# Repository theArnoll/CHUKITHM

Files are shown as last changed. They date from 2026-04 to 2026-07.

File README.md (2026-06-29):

# A touch controller based on a Japanese Arcade

English version | [繁體中文版本 (Traditional Chinese version)](README_zh-TW.md)

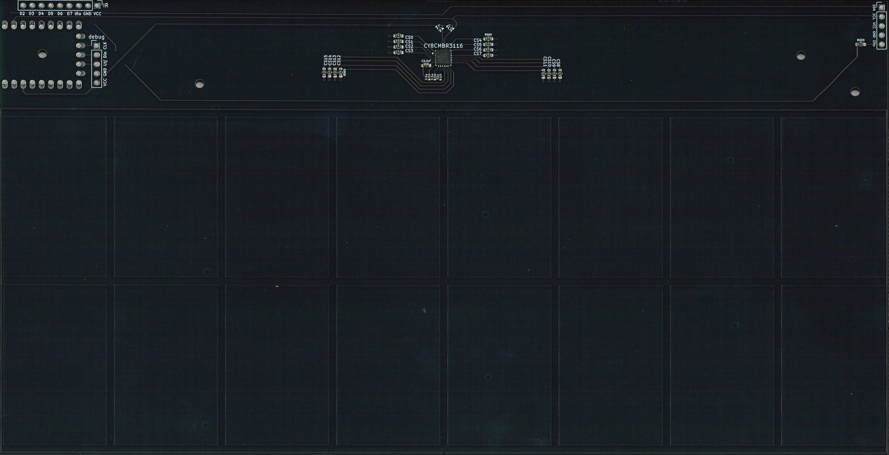
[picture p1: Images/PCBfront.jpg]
PCB Front image

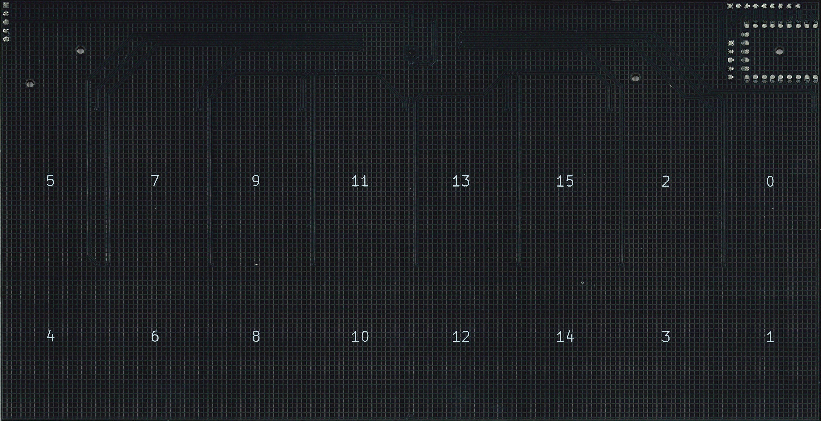
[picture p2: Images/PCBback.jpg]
PCB Back image


## Table of Contents

- [A touch controller based on a Japanese Arcade](#a-touch-controller-based-on-a-japanese-arcade)
  - [Table of Contents](#table-of-contents)
  - [BOM](#bom)
  - [Development platform](#development-platform)
    - [This project is develop with PlatformIO + Arduino C++ code](#this-project-is-develop-with-platformio--arduino-c-code)
  - [Third Party Libraries](#third-party-libraries)
  - [Sensing Concepts, PCB Design, and Dimensional References (Japanese)](#sensing-concepts-pcb-design-and-dimensional-references-japanese)
  - [Usage](#usage)
    - [Software Prerequisite](#software-prerequisite)
    - [Step](#step)
    - [Enabling Keyboard Input](#enabling-keyboard-input)
  - [Prototype Touchpad Making Step](#prototype-touchpad-making-step)
  - [Program flow chart](#program-flow-chart)
    - [Config](#config)
    - [Running code (`CY8C_code.ino`)](#running-code-cy8c_codeino)
  - [Development stage](#development-stage)
  - [AI Usage \& Attribution](#ai-usage--attribution)

## BOM

1. [PCB](./PCB/FormalPCB/Touchpad.kicad_pcb) × 2
   1. CY8CMBR3116 × 1
   2. 0.1uF × 2
   3. 1uF × 1
   4. 2.2nF X7R × 1
   5. 4.7kΩ × 2
   6. 560Ω × 16
2. IR LED × 6 `! Function haven't implented yet`
3. ~IRM-3638~ TSSP58038 IR reciever × 6 `! Function haven't implented yet, likely to switch to TSSP58038`
4. RP2040-Zero × 1 (Refer as RP2040 below)
   1. Machined Pin Header 9 pin × 2
   2. Machined Female Header 9 pin × 2
   3. Machined Pin Header 5 pin × 1
   4. Machined Female Header 5 pin × 1
5. [Acrylic case](./Case/Acrylic.dwg) for touch pads (2mm thick) × 2
   1. [Acrylic cap](./Case/AcrylicCap.dwg) for covering CY8CMBR3116 (2mm thick) × 1
   2. M2 screw (10mm length) × 6
      1. M2 Hex Nut × 6
      2. M2 Washer (Rubber recommended) × 6
   3. M3 screw (≥9mm length) × 7
      1. M3 Hex Nut × 7
      2. M3 Washer (Rubber recommended) × 7

    2mm thick acrylic × 2 + 1.6mm PCB = 5.6mm thick in total.
    5.6mm + 1.6mm M2 nut + 0.5mm rubber washer = 7.7mm
    5.6mm + 2.4mm M3 nut + 0.5mm rubber washer = 8.5mm
<!-- TODO: update IR info here after IR has been implented -->

<details>

<summary>Using test PCB</summary>

1. Testing PCB [motherboard type B](./PCB/TestPCB/TestMotherboardB.kicad_pcb) × 1
2. Testing PCB [childboard type B](./PCB/TestPCB/TestChildboardB.kicad_pcb) × 1
   1. CY8CMBR3116 w/ [DIP convertion board](./PCB/CY8CMBR3116_PCB/CY8CMBR3116_PCB.kicad_pro) × 1 `! The KiCad project is created with KiCad version 9 or 8.`
   2. 0.1uF × 2
   3. 1uF × 1
   4. 2.2nF X7R × 1
   5. 4.7kΩ × 2
   6. 560Ω × 16
3. IR LED `! Function haven't implented yet`
4. ~IRM-3638~ TSSP58038 IR reciever `! Function haven't implented yet, likely to switch to TSSP58038`
5. RP2040-Zero × 1
   (Refer as RP2040 below)

</details>

<details>

<summary>Using handmade prototype touchpad</summary>

1. CY8CMBR3116 w/ DIP convertion board × 1
   1. 0.1uF × 2
   2. 1uF × 1
   3. 2.2nF × 1
   4. 4.7kΩ × 2
2. Capacitive touch pad × 1 set
   1. Double side conductive copper tape (making how-to look below)
   2. 560Ω × 6/set or 8/set according to [which you choose](#prototype-touchpad-making-step)
3. IR LED `! Function haven't implented yet`
4. ~IRM-3638~ TSSP58038 IR reciever `! Function haven't implented yet, likely to switch to TSSP58038`
5. RP2040-Zero × 1
   (Refer as RP2040 below)

</details>

## Development platform

### This project is develop with PlatformIO + Arduino C++ code

<!-- TODO: explain it more -->

1. VSCode -> Extensions, install PlatformIO
2. Add project: each project folder in this Repo <!-- for ex: [Code/IRcode](Code/IRcode) -->

## Third Party Libraries

Big thank to the author(s) of these libraries

- [CypressCY8CMBR3116](https://github.com/sebastianregelmann/CypressCY8CMBR3116) by GitHub [@sebastianregelmann](https://github.com/sebastianregelmann)
    The way installing the library:
  1. Download the repo as `.zip`
  2. Rename the `.zip` as `CypressCY8CMBR3116.zip`
  3. Arduino IDE 2 > Sketch > Library > Include Library > Add .ZIP Libray...
  4. Navigate to the .zip and select it to install the library.
  5. !IMPORTANT! Current version of this library need to edit the .cpp file to be able to run correctly. Here's how to fix:
      1. Navigate to line 699, where `uint8_t CY8CMBR3116::activateSettings() {` is at
      2. After `uint8_t error = calculateCRC();`, add a line and write `delay(250);`.
      3. After `error = applyRegister();` and `error = resetIC();`, add a line and write `delay(200);`.

      This will increase the possibility of the setting being activated if nothing seem to go wrong.

- [Arduino-Pico](https://github.com/earlephilhower/arduino-pico)
  For developing RP2040-Zero with Arduino IDE and Arduino code.  
  Install the board:
  1. `Arduino IDE 2` > `Arduino IDE` > `Preference` > `Additional boards manager URLs:`
   Add below in the end:
   ```
   https://github.com/earlephilhower/arduino-pico/releases/download/global/package_rp2040_index.json
   ```
  2. `Arduino IDE 2` > `Boards Manager`
  Search "RP2040", install "Raspberry Pi Pico/RP2040/RP2350" by "Earle F. Phithower, III".
  - Adafruit TinyUSB library is going to install along installing this board.  
  The library for USB communication with the computer in [CY8C_code/NKRO_TinyUSB.h](./Codes/forCY8C/CY8C_code/NKRO_TinyUSB.h).  
  ***HOWEVER***, before flashing [CY8C_code.ino](./Codes/forCY8C/CY8C_code/CY8C_code.ino), please go to `Arduino IDE 2` > `Tools` > `USB Stack` > `Adafruit Tiny USB` to switch USB function.

## Sensing Concepts, PCB Design, and Dimensional References (Japanese)

[Full dimensions and informations](https://mizucoffee.blogspot.com/2018/05/1-chunithm.html) (Blog, multiple pages)  
[Detailed dimensions and sensing method](https://gist.github.com/mizucoffee/2f6263656d174fb2284a9e49c44bfabc)  
[Touch panel (ground slider) length](https://detail.chiebukuro.yahoo.co.jp/qa/question_detail/q14172146159)  
[Sensing method](https://x.com/QmanEnobikto/status/2049293495903629316) (Newer information as confirmation)  

## Usage

### Software Prerequisite

- Arduino IDE (Tested v.2.3.8 on Windows 11 & macOS Tahoe)
  Have the third party library mentioned above installed (either install via .zip or install in the Library Manager in Arduino IDE and make sure you're installing "CypressCY8CMBR3116 by sebastianregelmann".)

### Step

1. Wire your CY8CMBR3116 well on breadboard. I²C SDA → Pin 0, I²C SCL → Pin 1. Make sure you've pulled these pins up with 4.7kΩ resistor.
2. Connect your RP2040 to your computer with a USB cable.
3. Upload [ConfigCode.ino](./CY8C_code/ConfigCode/ConfigCode.ino)
4. Upload [CY8C_code.ino](./CY8C_code/CY8C_code/CY8C_code.ino)
5. Open serial monitor and tap the touch pad.

### Enabling Keyboard Input

Ground Pin 8 on your RP2040 to enable keyboard input.

## Prototype Touchpad Making Step

Prepare a wooden board, print the image below that need to ensure the thickness of black line in the image are 8mm, and paste the paper with white glue.

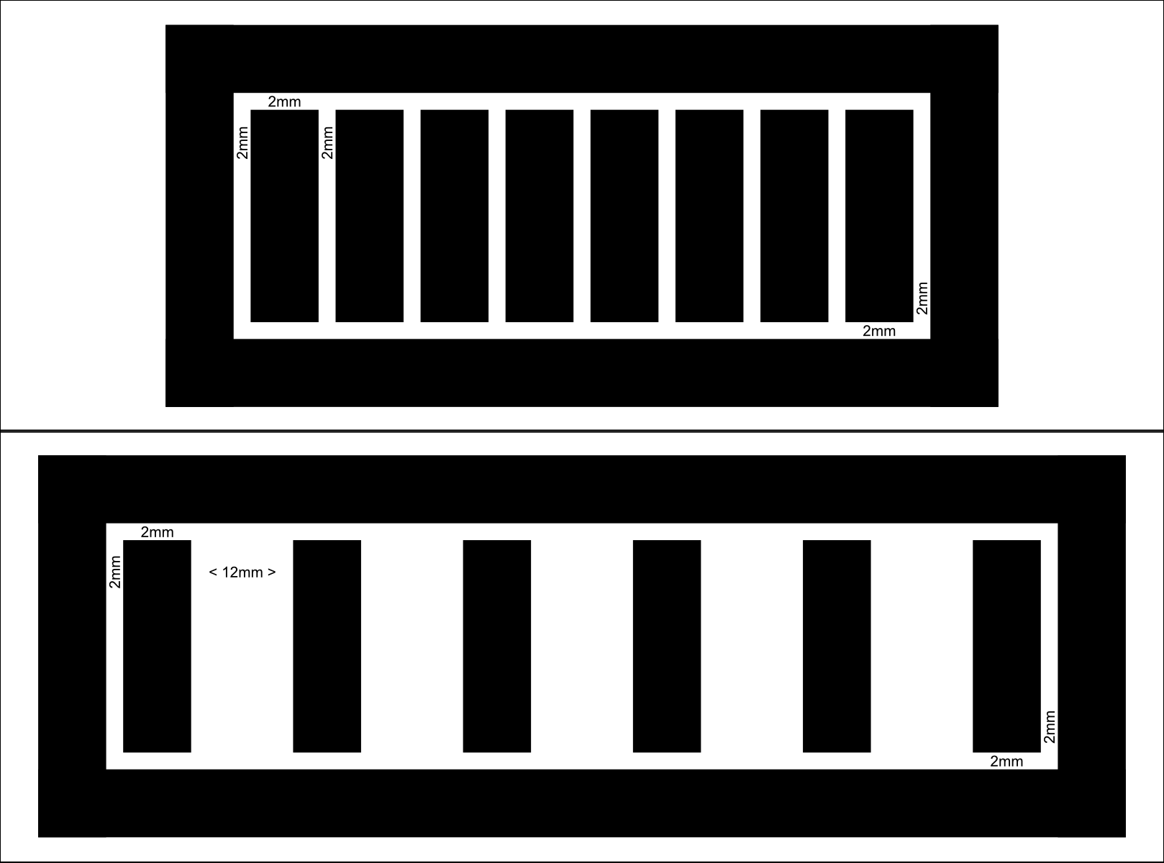
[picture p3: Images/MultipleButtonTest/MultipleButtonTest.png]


Choose one of the designs to test the result. The sticks in the middle are touch buttons, and the outter ring is ground. The 6 touch buttons one is good for playing rhythm games on PC.

After you decided the pattern you want to test, cover the black area with 8mm width copper tape and solder wires to these to pins:

- Touch buttons → CS0 ~ CS5 on CY8CMBR3116 via a 560Ω resistor. (CS0 ~ CS7 if you choose 8 buttons one)
- Ground → GND on RP2040

Beware that the space between touch pad and ground ring is the maximum distance between your finger and the touch pad that can be detected as touched.

## Program flow chart

Only Chinese version is available at the time.

### Config



### Running code (`CY8C_code.ino`)


<!-- ![Images/FlowChart/CY8C_Code_setup.svg](Images/FlowChart/CY8C_Code_setup.svg)
![Images/FlowChart/CY8C_Code_loop.svg](Images/FlowChart/CY8C_Code_loop.svg) -->

## Development stage

- [X] Configuration
- [X] Start sensing and print something that makes some sort of sense (≈ MVP)
- [X] Introduce `HID-Project.h`
- [X] Test multiple buttons
- [X] Test IR Code
- [X] Improve latency → Latency is now improved from around 70~75ms to around 40 ms. (Updated 2026 May 11, 1st update)
- [X] Finish IR Code <!-- TODO: To be test -->
- [X] Print and test PCB
- [X] Finalize PCB design
      Integrating CY8CMBR3116 the IC itself to the PCB and include RP2040 to the PCB itself.
      Find the solution of IR sensing connection to the motherboard.
- [ ] Finalize the case
- [ ] Refine the README and documents and Public the Repo
   - [ ] Upload photos and close source pictures to Imgur
   - [ ] Document the usage of CY8CMBR3116 in the same or another repo
   - [X] Public the repo
   - [ ] Refine the final README

---

## AI Usage & Attribution

This project incorporates AI-assisted development tools to optimize workflow and efficiency:

* **Code Completion**: GitHub Copilot and Continue + `granite4:7b-a1b-h` (VS Code) were used for real-time autocompletion.
* **Architectural Scaffolding**: Leveraged `phi4:14b` and `phi4-reasoning:14b` for generating initial boilerplate code and verifying logic in remote environments where hardware access was limited.
* **Information Verification**:
  * Google Gemini was utilized for conceptual research and documentation verification (no project source code was uploaded to Gemini platform)
  * Gemini models and Gemma 4 models on Google AI Studio is used, with paid API key used to ensure legal data privacy.

All AI-generated code has been manually reviewed, refactored, and tested to ensure logic integrity and project-specific requirements.



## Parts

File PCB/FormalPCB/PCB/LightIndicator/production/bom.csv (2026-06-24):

Designator | Footprint | Quantity | Value | LCSC Part #
1KΩ_20, 1KΩ_19, 1KΩ_18, 1KΩ_17, 1KΩ_16, 1KΩ_15, 1KΩ_14, 1KΩ_13, 1KΩ_12, 1KΩ_11, 1KΩ_10, 1KΩ_9, 1KΩ_8, 1KΩ_7, 1KΩ_6, 1KΩ_5, 1KΩ_4, 1KΩ_3, 1KΩ_2, 1KΩ | 0402 | 20 | R_0402_1005Metric | C11702
74HC595_3, 74HC595_2, 74HC595 | SOIC-16_3.9x9.9mm_P1.27mm | 3 | SOIC-16_3.9x9.9mm_P1.27mm | C5947
BARGRAPH+_2, BARGRAPH+, BARGRAPH-_2, BARGRAPH- | PinHeader_1x20_P2.54mm_Vertical | 4 | PinHeader_1x20_P2.54mm_Vertical
C.1Μ_3, C.1Μ_2, C.1Μ | 0402 | 3 | C_0402_1005Metric_Pad0.74x0.62mm_HandSolder | C1525

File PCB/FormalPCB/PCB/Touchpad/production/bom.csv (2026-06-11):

Designator | Footprint | Quantity | Value | LCSC Part #
C.1Μ_2, C.1Μ | 0402 | 2 | C_0402_1005Metric_Pad0.74x0.62mm_HandSolder | C1525
C1Μ | 0402 | 1 | C_0402_1005Metric_Pad0.74x0.62mm_HandSolder | C52923
C2.2NF | 0603 | 1 | C_0603_1608Metric_Pad1.08x0.95mm_HandSolder | C15849
CY8CMBR3116 | QFN-24-1EP_4x4mm_P0.5mm_EP2.65x2.65mm_ThermalVias | 1 | (footprint {dblquote}Package_DFN_QFN:QFN-24-1EP_4x4mm_P0.5mm_EP2.6x2.6mm{dblquote} | C914913
R220 | 0603 | 1 | R_0603_1608Metric_Pad0.98x0.95mm_HandSolder | C22962
R4.7K_2, R4.7K | 0402 | 2 | C_0402_1005Metric_Pad0.74x0.62mm_HandSolder | C25900
R560_16, R560_15, R560_14, R560_13, R560_12, R560_11, R560_10, R560_9, R560_8, R560_7, R560_6, R560_5, R560_4, R560_3, R560_2, R560 | 0603 | 16 | R_0603_1608Metric_Pad0.98x0.95mm_HandSolder | C23204

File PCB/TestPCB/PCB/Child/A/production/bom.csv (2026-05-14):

Designator | Footprint | Quantity | Value | LCSC Part #
REFFC | Amphenol_F32R-1A7x1-11010_1x10-1MP_P0.5mm_Horizontal | 1 | Amphenol_F32R-1A7x1-11010_1x10-1MP_P0.5mm_Horizontal | C3169434

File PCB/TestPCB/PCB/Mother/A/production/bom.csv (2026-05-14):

Designator | Footprint | Quantity | Value | LCSC Part #
C.1Μ_2, C2.2NF | 0603 | 2 | C_0603_1608Metric_Pad1.08x0.95mm_HandSolder | C15849
C.1Μ | 0603 | 1 | C_0603_1608Metric_Pad1.08x0.95mm_HandSolder | C1525
C1Μ | 0603 | 1 | C_0603_1608Metric_Pad1.08x0.95mm_HandSolder | C52923
CONNECTION | PinHeader_1x04_P2.54mm_Vertical | 1 | PinHeader_1x04_P2.54mm_Vertical
R4.7K_2, R4.7K | 0603 | 2 | R_0603_1608Metric_Pad0.98x0.95mm_HandSolder | C25900
R560_16, R560_15, R560_14, R560_13, R560_12, R560_11, R560_10, R560_9, R560_8, R560_7, R560_6, R560_5, R560_4, R560_3, R560_2, R560 | 0603 | 16 | R_0603_1608Metric_Pad0.98x0.95mm_HandSolder | C23204
REFFC | Amphenol_F32R-1A7x1-11010_1x10-1MP_P0.5mm_Horizontal | 1 | Amphenol_F32R-1A7x1-11010_1x10-1MP_P0.5mm_Horizontal | C3169434

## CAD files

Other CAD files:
Case/AcrylicCap.dwg
Case/Acrylic.dwg

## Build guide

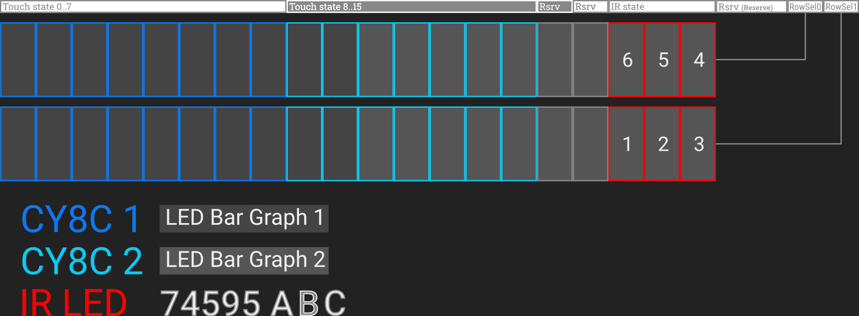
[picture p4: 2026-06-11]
Images/BarGraphView&BitAllocation/LED_Bar_Graph_usage.png

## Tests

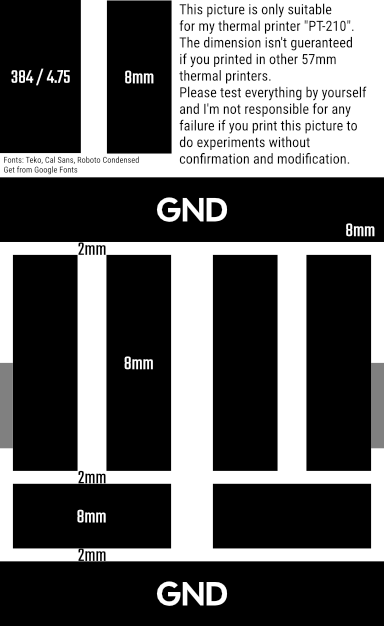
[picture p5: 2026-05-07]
Images/Little 2-row test/Little 2-row test.png

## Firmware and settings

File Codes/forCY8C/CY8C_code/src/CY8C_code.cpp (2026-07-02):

#include <CypressCY8CMBR3116.h>
#include <Wire.h>
#include "NKRO_TinyUSB.h" // TinyUSB NKRO
#include <Adafruit_NeoPixel.h>
#include <SPI.h>
#include "hardware/pwm.h" // RP2040 Hardware PWM

#define elif else if

#define I2C_ADDRESS 0x51     //I2C Address of the Cypress IC (0x37 is default)
#define REQUEST_TIMEOUT 40   //After how many request is a Timeout triggered

CY8CMBR3116 touchIC(I2C_ADDRESS, REQUEST_TIMEOUT);
CY8CMBR3116 touchIC2(I2C_ADDRESS + 1, REQUEST_TIMEOUT);
Adafruit_NeoPixel pixels(1, 16, NEO_GRB + NEO_KHZ800);

void printError(uint8_t errorCode)
{
    Serial.print("Communication Error ");
    switch (errorCode)
    {
        case 1: Serial.println("1: Data too long to fit in transmit buffer");
                pixels.setPixelColor(0, pixels.Color(255, 0, 0)); pixels.show(); break; // red
        case 2: Serial.println("2: Received NACK on transmit of address"); 
                pixels.setPixelColor(0, pixels.Color(0, 255, 0)); pixels.show(); break; // green
        case 3: Serial.println("3: Received NACK on transmit of data"); 
                pixels.setPixelColor(0, pixels.Color(0, 0, 255)); pixels.show(); break;  // blue
        case 4: Serial.println("4: Other Error");
                pixels.setPixelColor(0, pixels.Color(255, 255, 0)); pixels.show(); break; // yellow
        case 5: Serial.println("5: Timeout Error"); 
                pixels.setPixelColor(0, pixels.Color(255, 0, 255)); pixels.show(); break; // purple
        default:
            Serial.print("Unknown: Unknown Wire Error ");
            Serial.println(errorCode);
            pixels.setPixelColor(0, pixels.Color(255, 255, 255)); pixels.show();
            break;
    }
}

void requestTouchStatus(uint8_t statusStorage[2][2])
{
    uint8_t touchStatusBuffer[2][2];

    uint8_t error = touchIC.get_BUTTON_STAT(touchStatusBuffer[0]);
    if (error != 0) { Serial.print("IC1 Request Touch Status Loop: "); printError(error); }
                else { pixels.clear(); pixels.show(); }

    error = touchIC2.get_BUTTON_STAT(touchStatusBuffer[1]);
    if (error != 0) { Serial.print("IC2 Request Touch Status Loop: "); printError(error); }
                else { pixels.clear(); pixels.show(); }

    for (uint8_t a = 0; a <= 1; a++)
    {
        for (uint8_t b = 0; b <= 1; b++)
            statusStorage[a][b] = touchStatusBuffer[a][b];
    }
}

void sendSPI(uint32_t data, uint8_t latchPin, uint8_t dataLength) {
    SPI1.beginTransaction(SPISettings(1000000, MSBFIRST, SPI_MODE0));
    digitalWrite(latchPin, LOW);
    switch (dataLength) {  
        case 1: case 8: SPI1.transfer(data & 0xFF); break;
        case 2: case 16: SPI1.transfer16(data & 0xFFFF); break;
        case 3: case 24: SPI1.transfer((data >> 16) & 0xFF); SPI1.transfer16(data & 0xFFFF); break;
        case 4: case 32: SPI1.transfer16((data >> 16) & 0xFFFF); SPI1.transfer16(data & 0xFFFF); break;
        default: break;
    }
    digitalWrite(latchPin, HIGH);
    SPI1.endTransaction();
}

#define CATHODE_TOP_ON    (1UL << 23) 
#define CATHODE_BOTTOM_ON (1UL << 22) 
#define CATHODE_BOTH_ON   0UL         

void runSingleDotMarquee(uint8_t delayTime) {
    for (int i = 0; i < 20; i++) {
        uint32_t marqueeData = (1UL << i); 
        marqueeData |= CATHODE_TOP_ON;     
        sendSPI(marqueeData, 12, 3);
        delay(delayTime);
    }
    for (int i = 0; i < 20; i++) {
        uint32_t marqueeData = (1UL << i); 
        marqueeData |= CATHODE_BOTTOM_ON;  
        sendSPI(marqueeData, 12, 3);
        delay(delayTime);
    }
}

void runDualBarGraph(uint8_t delayTime) {
    for (int i = 0; i < 20; i++) {
        uint32_t marqueeData = 0;
        for (int j = 0; j <= i; j++) marqueeData |= (1UL << j);     
        marqueeData |= CATHODE_BOTH_ON;    
        sendSPI(marqueeData, 12, 3); delay(delayTime);
    }
    for (int i = 19; i >= 0; i--) {
        uint32_t marqueeData = 0;
        for (int j = 0; j < i; j++) marqueeData |= (1UL << j);
        marqueeData |= CATHODE_BOTH_ON;
        sendSPI(marqueeData, 12, 3); delay(delayTime);
    }
}

void setup() {
    Serial.begin(250000);
    pixels.begin(); pixels.setBrightness(10);
    
    Wire.setSDA(0); Wire.setSCL(1);
    Wire.begin();   
    Wire.setClock(400000);  

    // Wait for IC to wake up
    delay(50);

    pinMode(15, INPUT_PULLUP); //7
    pinMode(14, INPUT_PULLUP); //8
    
    if (digitalReadFast(15))
    {
        uint32_t sysTime = millis();
        while (!Serial && millis() - sysTime < 2000) { delay(1); }  
        if (millis() - sysTime >= 2000)  
        {
            pixels.setPixelColor(0, pixels.Color(0, 255, 255)); pixels.show(); // Sky blue  
            delay(200); 
        }
    }
    
    Wire.beginTransmission(I2C_ADDRESS);
    if (Wire.endTransmission() == 0) Serial.println("IC 1 found");
    Wire.beginTransmission(I2C_ADDRESS + 1);
    if (Wire.endTransmission() == 0) Serial.println("IC 2 found");

    SPI1.setSCK(10); SPI1.setTX(11);
    SPI1.begin();
    pinMode(12, OUTPUT);

    // TODO: SW toggle Keyboard output
    KB.begin();

    runSingleDotMarquee(50);
    delay(100); 
    runDualBarGraph(50);

    // IR Pins
    for (uint8_t re = 2; re <= 7; re++)  // TSSP Pins
        pinMode(re, INPUT_PULLUP);

    gpio_set_function(8, GPIO_FUNC_PWM);
    uint slice_num = pwm_gpio_to_slice_num(8);  // Get Hardware PWM slice number
    pwm_set_clkdiv(slice_num, 125.0f);          // Set clock to 1MHz (125MHz / 125)
    pwm_set_wrap(slice_num, 26);                // Set frequency to ~38.4kHz (1MHz / 26)
    pwm_set_chan_level(slice_num, pwm_gpio_to_channel(8), 13);  // Set duty cycle to 2/26 (=1/13)
    pwm_set_enabled(slice_num, true);           // Start Hardware PWM

    digitalWrite(14, LOW);
    Serial.println("Start Program");
}

char keymap[2][2][8] = {  //   0    1    2    3    4    5    6    7
                        {   { '1', 'q', 'a', 'z', 'v', 'f', 'r', '4' } , // IC 1
                            { 'c', 'd', 'e', '3', 'x', 's', 'w', '2' }   },
                        {   { '5', 't', 'g', 'b', ',', 'k', 'i', '8' } , // IC 2
                            { 'm', 'j', 'u', '7', 'n', 'h', 'y', '6' }   } };
uint8_t lastStatus[2][2] = { { 0, 0 }, { 0, 0 } }; // 2 ICs
char IRkeymap[6] = { '.', 'l', 'o', '9', 'p', '0' };
bool lastIRstatus[6] = { 0 };

unsigned long lastmicroS = micros();

void loop() {
    uint8_t touchStatus[2][2];
    bool IRstatus[6];
    requestTouchStatus(touchStatus);

    bool needToSend = false;

    //  Serial print status
    for (uint8_t ICsel = 0; ICsel <= 1; ICsel++)
    {   if(digitalReadFast(15) == LOW)
        {
            Serial.print(ICsel + 1); Serial.print(": |");
            for (uint8_t re = 0; re < 2; re++)
            {   for (int pointer = 0; pointer < 8; pointer++)
                {
                    uint8_t pressed = touchStatus[ICsel][re] >> pointer & 0b00000001;
                    Serial.print((char)(pressed ? (pointer+'0') : '-'));
                    Serial.print("|");
                }
                if (!re) Serial.print(" |"); else Serial.println();
            }
        }
    }
    
    // Keyboard events
    for (uint8_t ICsel = 0; ICsel <= 1; ICsel++)
    {   if (digitalReadFast(14) == LOW && (lastStatus[ICsel][0] != touchStatus[ICsel][0] || lastStatus[ICsel][1] != touchStatus[ICsel][1]))
        {   for (uint8_t bfrsel = 0; bfrsel <= 1; bfrsel++)
            {   for (int pointer = 0; pointer < 8; pointer++)
                {   uint8_t pressed = touchStatus[ICsel][bfrsel] >> pointer & 0b00000001,
                        lastPressed = lastStatus[ICsel][bfrsel]  >> pointer & 0b00000001;
                    
                    if(pressed && (pressed != lastPressed))
                    {
                        KB.add(keymap[ICsel][bfrsel][pointer]);
                        needToSend = true;
                        if(!digitalReadFast(15)) Serial.println(keymap[ICsel][bfrsel][pointer]);
                    }
                    else {
                        if(pressed != lastPressed)
                        {
                            KB.release(keymap[ICsel][bfrsel][pointer]);
                            needToSend = true;
                            if(!digitalReadFast(15)) { Serial.print("-"); Serial.println(keymap[ICsel][bfrsel][pointer]); }
                        }
                    }
                }  // end for in byte
            }  // end for in buffer
        }  // end if
    } // end for

    for (uint8_t re = 0; re < 6; re++)
    {
        IRstatus[re] = digitalReadFast(2 + re);

        if (IRstatus[re] != lastIRstatus[re]) 
        {                                      //  // * in TSSP, 0 = blocked and no IR input, 1 = Detected IR
            if (lastIRstatus[re] > IRstatus[re]) // 1 -> 0
                KB.release(IRkeymap[re]);
            elif (lastIRstatus[re] < IRstatus[re]) // 0 -> 1
                KB.add(IRkeymap[re]);
            needToSend = true;
        }
    }

    // if (digitalReadFast(15) == LOW)
    // {
        Serial.print("IR State: | ");
        for (uint8_t re = 0; re < 6; re++)
        {
            Serial.print((int)IRstatus[re]);
            Serial.print(" | ");
        }
        Serial.println();
    // }

    if (needToSend) KB.send();

    for(uint8_t ICsel = 0; ICsel <= 1; ICsel++)
    {   for(uint8_t reg = 0; reg <= 1; reg++)
            lastStatus[ICsel][reg] = touchStatus[ICsel][reg];
    }
    for(uint8_t re = 0; re < 6; re++)
        lastIRstatus[re] = IRstatus[re];

	if (!digitalReadFast(15))
    {   Serial.println(micros() - lastmicroS);
        lastmicroS = micros();
    }
}

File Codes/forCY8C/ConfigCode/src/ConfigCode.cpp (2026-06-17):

#include <CypressCY8CMBR3116.h>
#include <Wire.h>

//   -------------------------------------------
//  / Official Configure Example but Modified /
// -------------------------------------------

#define I2C_ADDRESS 0x52     //I2C Address of the Cypress IC (0x37 is default)
#define REQUEST_TIMEOUT 40   //After how many request is a Timeout triggered
#define NEW_I2C_ADDRESS 0x52 //I2C Address after programm. IC needs to be reseted for changes to apply
#define LED_BUILTIN 10

//Create an instance of the IC
CY8CMBR3116 touchIC(I2C_ADDRESS, REQUEST_TIMEOUT);

void printError(uint8_t errorCode) {  // Error 1 ~ 5 & default
    Serial.println("Error in communication:");
    switch (errorCode) {
        case 1:
            Serial.println("Error 1: data too long to fit in transmit buffer");
            break;
        case 2:
            Serial.println("Error 2: received NACK on transmit of address");
            break;
        case 3:
            Serial.println("Error 3: received NACK on transmit of data");
            break;
        case 4:
            Serial.println("Error 4: undefined Error");
            break;
        case 5:
            Serial.println("Error 5: timeout Error");
            break;
        default:
            Serial.println("Error not a Wire Error");
            break;
    }
}

uint8_t configureSensors() {  // SENSOR_EN, FFS_EN, SENSIVITY, THRESHOLD
    Serial.println("Set SENSOR_EN settings");
    //Enables/Disables senosrs 1 = Enabled, 0 = Disabled
    uint8_t SENSOR_0_7 = 0b11111111;   //Configures sensor enabled MSB = 7 LSB = 0
    uint8_t SENSOR_8_15 = 0b11111111;  //Configures sensor enabled MSB = 15 LSB = 8

    //Sends the databuffer to the touch IC
    uint8_t SENSOR_EN_BUFFER[2] = { SENSOR_0_7, SENSOR_8_15 };
    uint8_t error = touchIC.set_SENSOR_EN(SENSOR_EN_BUFFER);

    //when something went wrong return the error
    if (error != 0) {
        return error;
    }

    Serial.println("Set FFS_EN settings");
    //Enables/Disables FFS
    SENSOR_0_7 = 0x00;   //Configures sensor enabled MSB = 7 LSB = 0
    SENSOR_8_15 = 0x00;  //Configures sensor enabled MSB = 15 LSB = 8

    //Sends the databuffer to the touch IC
    uint8_t SENSOR_FFS_BUFFER[2] = { SENSOR_0_7, SENSOR_8_15 };
    error = touchIC.set_FFS_EN(SENSOR_FFS_BUFFER);

    //when something went wrong return the error
    if (error != 0) {
        return error;
    } else digitalWrite(10, 1);
    

    Serial.println("Set SENSITIVITY settings");
    //Sets the Sensitivity for each sensor
    uint8_t SENSITIVITY_0_3 = 0b11111111;    //first two bytes sensitivity for sensor 3; second two bytes sensitivity for sensor 2; ...
    uint8_t SENSITIVITY_4_7 = 0b11111111;    //first two bytes sensitivity for sensor 4; second two bytes sensitivity for sensor 7; ...
    uint8_t SENSITIVITY_8_11 = 0b11111111;   //first two bytes sensitivity for sensor 8; second two bytes sensitivity for sensor 11; ...
    uint8_t SENSITIVITY_12_15 = 0b11111111;  //first two bytes sensitivity for sensor 12; second two bytes sensitivity for sensor 15; ...

    //Sends the settings to the touch IC
    uint8_t SENSITIVITY_BUFFER[4] = { SENSITIVITY_0_3, SENSITIVITY_4_7, SENSITIVITY_8_11, SENSITIVITY_12_15 };
    error = touchIC.set_SENSITIVITY_all(SENSITIVITY_BUFFER);
    if (error != 0) {
        return error;
    }

    Serial.println("Set THRESHOLD settings");
    //Send threshold settings to touch IC
    uint8_t THRESHOLD_BUFFER[16] = { 140 };  //From index 0-15 the threshold value for sensor 0-15
    error = touchIC.set_THRESHOLD(THRESHOLD_BUFFER);
    if (error != 0) {
        return error;
    }

    // Below: Other settings that are not in the official example but are recommended to be set for better performance and user experience

    Serial.println("+ Set REFRESH_CTRL settings");
    uint8_t val_REFRESH = 0x01; // 20ms scan period / refresh period
    error = touchIC.set_REFRESH_CTRL(&val_REFRESH);
    if (error != 0) {
        return error;
    }

    Serial.println("+ Set DEVICE_CFG2 settings (Disableing button auto-reset)");
    uint8_t val_CFG2 = 0b00001000; // Disable button auto-reset (default 1 is going to make the button report as untouched even if the finger is still touching after 5 seconds)
    error = touchIC.set_DEVICE_CFG2(&val_CFG2);
    if (error != 0) {
        return error;
    }

    Serial.println("+ Set SENSOR_DEBOUNCE settings");
    uint8_t val_DEBOUNCE = 0x01; // Minimize debounce (the defaut 3 is likely to triple the 20ms refresh period, which is going to increase the latency.)
    error = touchIC.set_SENSOR_DEBOUNCE(&val_DEBOUNCE);
    if (error != 0) {
        return error;
    }

    Serial.println("+ Set STATE_TIMEOUT settings");
    uint8_t val_TIMEOUT = 0x3F; // Keep wake for 63 second
    error = touchIC.set_STATE_TIMEOUT(&val_TIMEOUT);
    if (error != 0) {
        return error;
    }

    Serial.println("+ Set SPO settings");
    uint8_t val_SPO_CFG = 0x10; // Make CS15 become CS and no longer HI'
    error = touchIC.set_SPO_CFG(&val_SPO_CFG); 
    if (error != 0) {
        return error;
    }

    Serial.println("+ 強制關閉系統自檢 (DEVICE_CFG1)");
    // 根據 TRM 第 90 頁，DEVICE_CFG1 的 Bit 0 是 SYSD_EN (預設為 1)
    // 設為 0x00 代表強行關閉自我診斷，不准晶片自動關閉寄生電容過大的按鍵！
    uint8_t val_CFG1 = 0x00; 
    error = touchIC.set_DEVICE_CFG1(&val_CFG1);

    //Return the final error Code
    return error;
}

uint8_t configureAddress() {  // Set I²C address to 0x51
    Serial.println("Set I2C_ADDRESS settings");
    //sets a new I2C Address
    uint8_t I2C_ADDRESS_BUFFER[1] = {NEW_I2C_ADDRESS};
    uint8_t error = touchIC.set_I2C_ADDR(I2C_ADDRESS_BUFFER);
    return error;
}

void configueTouchIC() {
    Serial.println("Configuring sensor settings ...");

    delay(250);
    //Configure sensor settings
    uint8_t error = configureSensors();
    if (error != 0) {
        Serial.println("Error while configuring sensor settings");
        printError(error);
        return;
    } else {
        Serial.println("Configuring sensor settings succsessfull");
    }

    delay(250);
    //Configure I2C Address
    error = configureAddress();
    if (error != 0) {
        Serial.println("Error while configuring I2C address");
        printError(error);
        return;
    } else {
        Serial.println("Configuring I2C address succsessfull");
    }

    delay(250);
    //apply the changes and restart the touch IC
    error = touchIC.activateSettings();
    if (error != 0) {
        Serial.println("Error while activating new register");
        printError(error);
        return;
    } else {
        Serial.println("Activating new register succsessfull");
    }
    Serial.println("Configuring succsessfull ...");
}
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

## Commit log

2026-04-29 Swtich to Arduino Pro Micro and from SquidHID to HID-Project
2026-05-03 Turn off FSS, improve speed
    Turned off FSS to enable multiple button touch, Sped up Wire (I2C) speed, remove delay() in loop() and change keymap.
2026-05-07 Improve performance and add more
    + IR LED RX/TX test code
    + PCB Files for experiment
    PCB Files isn't tested. It's not even finished.
    [TestPCB.kicad_pcb, TestPCB.kicad_sch]
2026-05-10 Organize code & improve latency
    + IMPROVED LATENCY from 70~75ms to 40ms
    - Removed old unused code
    + A few comments
    + 3rd party library tweak method on README.md
    [TestPCB.kicad_pcb]
2026-05-12 Move configurations
    [TestChildBoardA.kicad_pcb, TestMotherboard.kicad_pcb]
2026-05-13 Test PCB Finished
    [TestChildBoardA.kicad_pcb, TestChildboardB.kicad_pcb, TestMotherboard.kicad_pcb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]
2026-05-14 Modify test pcb, add flow chart
    [TestChildBoardA.kicad_pcb, TestChildboardB.kicad_pcb, TestMotherboardA.kicad_pcb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]
2026-05-25 PCB, switch to RP2040 Zero, codes, file struct update
    1. Updated PCB file, confirmed current PCB design and output Gerber files. (the Gerber have been manufactured and tested. Version B works better.)
    2. Updated both code to switch board to RP2040 Zero and improve function
    3. Minor file structure changing to improve location clarity
    [CY8CMBR3116_PCB-B_Cu.gbr, CY8CMBR3116_PCB-B_Mask.gbr, CY8CMBR3116_PCB-B_Paste.gbr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]
2026-05-26 Arranged code, rename vars, update MD
    - Code
    - Removed some line breakings
    - Renamed some variables
    - Fixed low level problem
    - Documents
    - Add table of contents
    - Add zh-TW README
    [CY8C_code.ino]
2026-06-02 Start making final PCBs
    [CY8CMBR3116_PCB-B_Cu.gbr, CY8CMBR3116_PCB-B_Mask.gbr, CY8CMBR3116_PCB-B_Paste.gbr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]
2026-06-06 PCB Large update & ready for LED debug board
    [LightIndicator.kicad_pcb, Motherboard.kicad_pcb, Touchpad(backup).kicad_pcb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]
2026-06-09 Test SPI, regenerate IR code, complete PCB design
    [BOM-Touchpad.csv, LightIndicator.kicad_pcb, Touchpad.kicad_pcb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]
2026-06-11 Add PlatformIO possibility and update README.md in both language
    [BOM-Touchpad.csv, CY8CMBR3116_PCB.kicad_pcb, LightIndicator.kicad_pcb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]
2026-06-16 Add case file and switch hardware development platform to PlatformIO
    [Acrylic.dwg, AcrylicCap.dwg]
2026-06-17 Update complete BOM, edit PCB design, upgrade ConfigCode to PlatformIO
    [LightIndicator.kicad_pcb, Touchpad.kicad_pcb]
2026-06-24 Update PCB and Finish basic IR code and basic integration
    [Acrylic.dwg, AcrylicCap.dwg, FormalPCB.kicad_pcb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]
2026-07-02 Update IR PWM duty cycle to a usable level
